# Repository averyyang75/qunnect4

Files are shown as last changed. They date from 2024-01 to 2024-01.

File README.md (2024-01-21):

# Qunnect4

---

Qunnect4 is designed as an educational board game rooted in the principles of quantum mechanics. With using simulated bichromatic photons, it illustrates the counterintuitive aspects of quantum phenomena and explains fundamental concepts such as superposition, collapse, and entanglement. By encapsulating quantum physics within a physical board game format, Qunnect4 bridges the mysterious realm of quantum physics with the classical world, providing a straightforward, interactive and hands-on experience.

## Construction of Apparatus

Qunnect4 consists of 42 tokens and 1 game board.

Each token is made with a PCB, assembled with one blue and one red LED, two resistors, four diodes, one radio transmitter and one receiver, four push buttons, and one battery holder. Powered by a battery, a token simulates a bichromatic photon. The token is superposed when turned on initially, emitting both blue and red LEDs. When a red or blue button is pushed, the token collapses, emitting only one LED.

The 42 tokens are grouped into 21 pairs. Each pair of tokens simulate a pair of “entangled photons”, with using the paired radio modules. Measuring one token will collapse both tokens simultaneously (one red and one blue).

The game board can be made with wood or foam board.

## Use of Apparatus

As a quantum adaptation of the popular game Connect 4, Qunnect4 is designed to provide hands-on experiences that help players quickly learn key quantum concepts such as superposition, collapse, and entanglement with ease.

Players are encouraged to use the apparatus in a manner like playing Connect 4, with following differences:

- In classic Connect 4, each player places 1 token each turn.
- In Qunnect 4, each player places a pair of entangled tokens each turn.
- A player may choose not to place tokens. Instead, the player can press a button to
collapse a pair of entangled tokens on board.
- To prevent a cycling condition, where one player always collapses the tokens placed by
the other, a player is not allowed to collapse a token unless its row or column is fully occupied. This rule ensures a fair and balanced gameplay experience for both players.

## Related Projects

[Qunnect4 Web](https://github.com/averyyang75/qunnect4-web) implements Qunnect4 in the web application format, offering cost-free accessibility and improved availability.

[Qunnect4 Web game](https://qunnect4.app) is online now.

&copy; Avery Yang

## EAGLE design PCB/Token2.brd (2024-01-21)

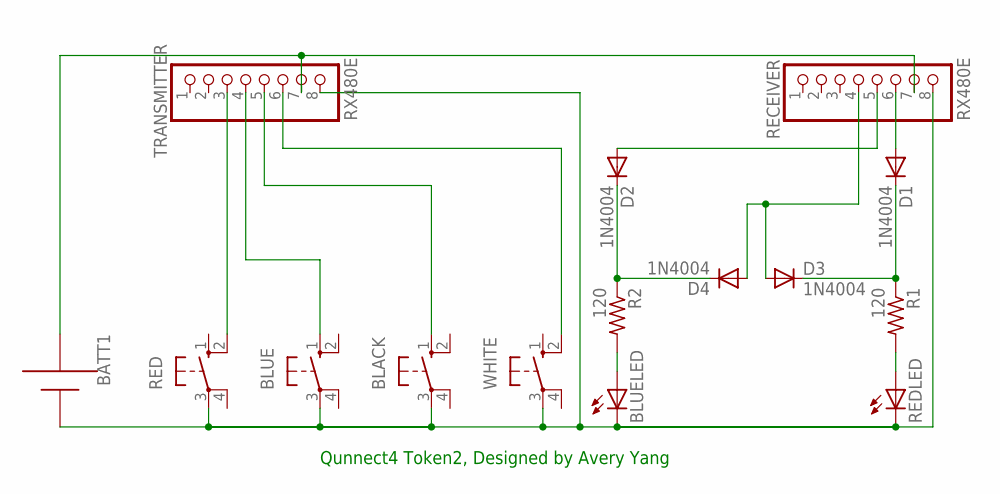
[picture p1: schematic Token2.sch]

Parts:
BATT1: AAA; 12BH412
BLACK: 10-XX; B3F-10XX
BLUE: 10-XX; B3F-10XX
BLUELED: LED5MM
D1, D2, D3, D4: 1N4004; DO41-10
R1, R2: 120; 0207/10
RECEIVER: RX480E; 1X08
RED: 10-XX; B3F-10XX
REDLED: LED5MM
TRANSMITTER: RX480E; 1X08
WHITE: 10-XX; B3F-10XX

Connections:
unnamed: BATT1.+, BLACK.3, BLUE.3, BLUELED.K (C), RECEIVER.8, RED.3, REDLED.K (C), TRANSMITTER.8, WHITE.3
unnamed: D2.C, D4.C, R2.1
unnamed: TRANSMITTER.6, WHITE.2 (S1)
unnamed: BLUE.1 (S), TRANSMITTER.4
unnamed: RED.2 (S1), TRANSMITTER.3
unnamed: BLACK.1 (S), TRANSMITTER.5
unnamed: D2.A, RECEIVER.5
unnamed: D1.A, RECEIVER.6
unnamed: D1.C, D3.C, R1.1
unnamed: R1.2, REDLED.A
unnamed: BLUELED.A, R2.2
unnamed: D3.A, D4.A, RECEIVER.4
unnamed: BATT1.-, RECEIVER.7, TRANSMITTER.7

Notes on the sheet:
Qunnect4 Token2, Designed by Avery Yang

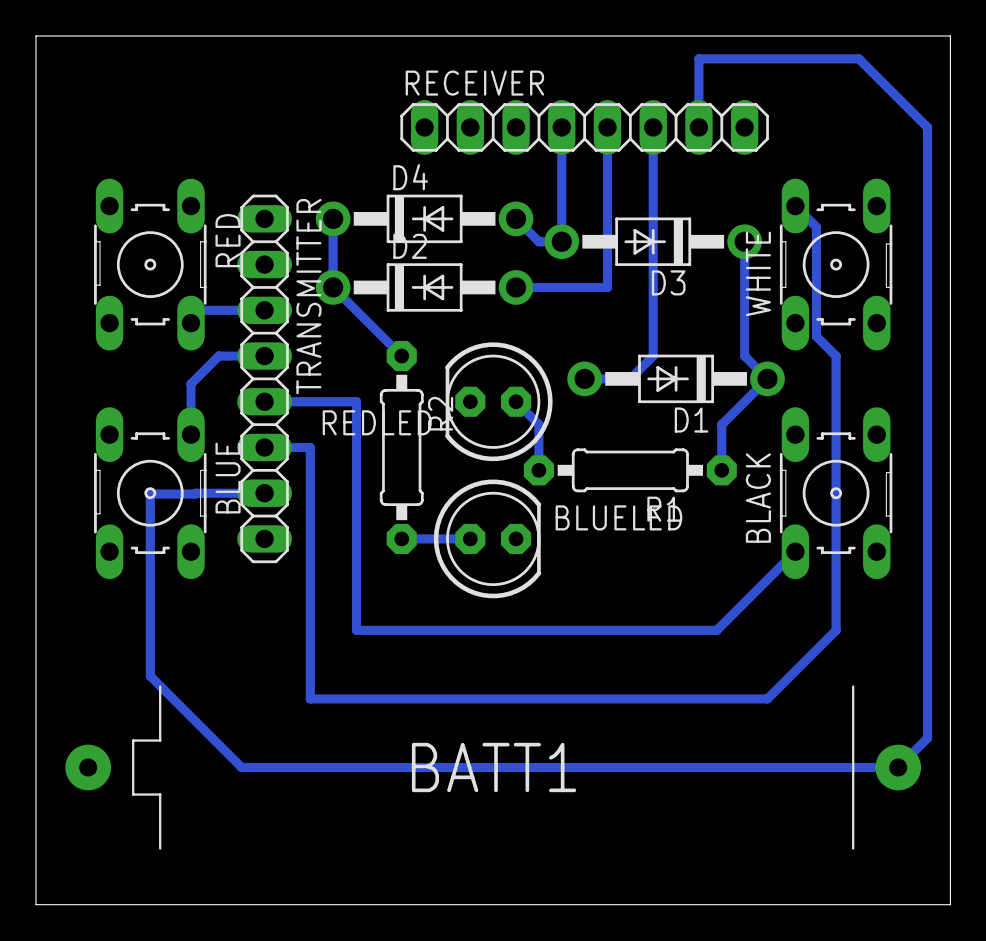
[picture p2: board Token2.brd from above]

Board: 2 copper layers, 50.8 x 48.3 mm, 15 parts (0 on the bottom side), 13 nets.

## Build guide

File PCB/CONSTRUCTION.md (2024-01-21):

# Construction

Each token is represented by a PCB. As tokens are grouped in pairs, there are two different designs of PCBs.

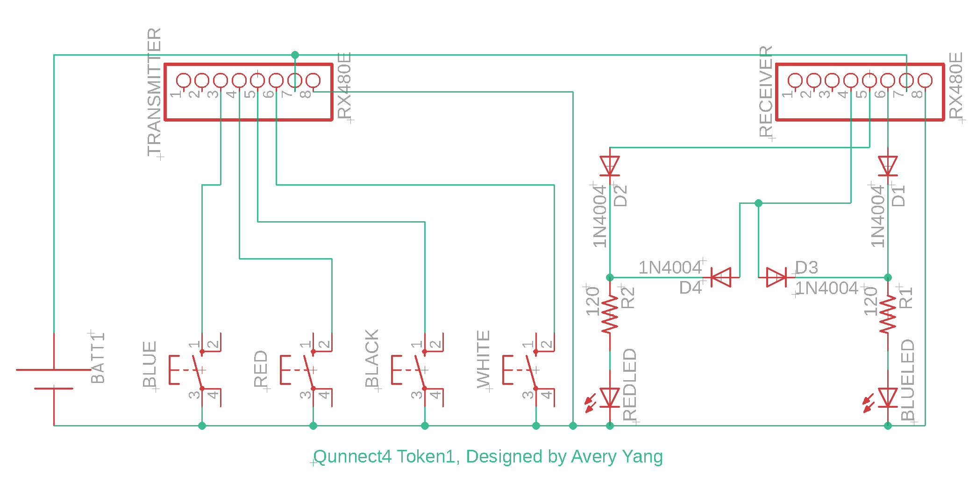
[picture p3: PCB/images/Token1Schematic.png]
Token 1 Schematic Design

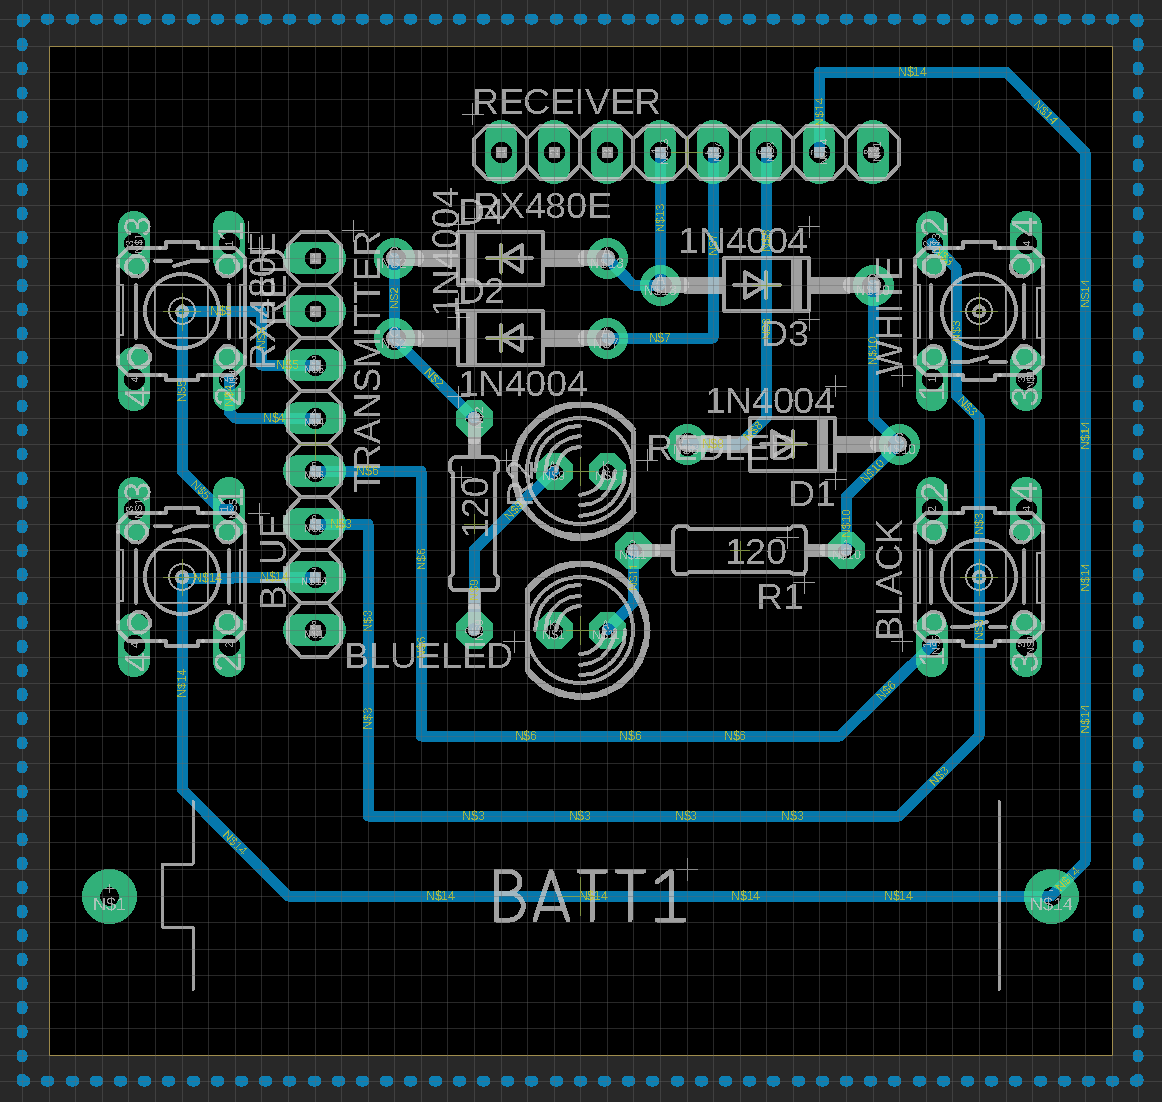
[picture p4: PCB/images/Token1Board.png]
Token 1 Board Design

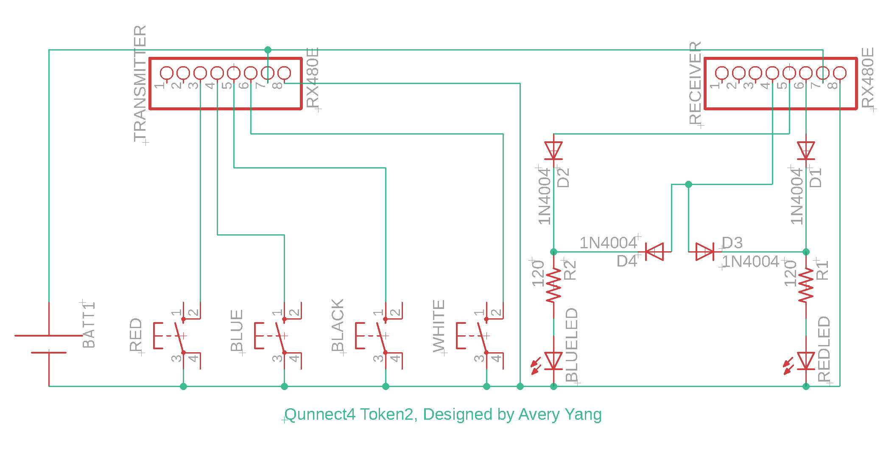
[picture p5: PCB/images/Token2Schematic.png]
Token 2 Schematic Design

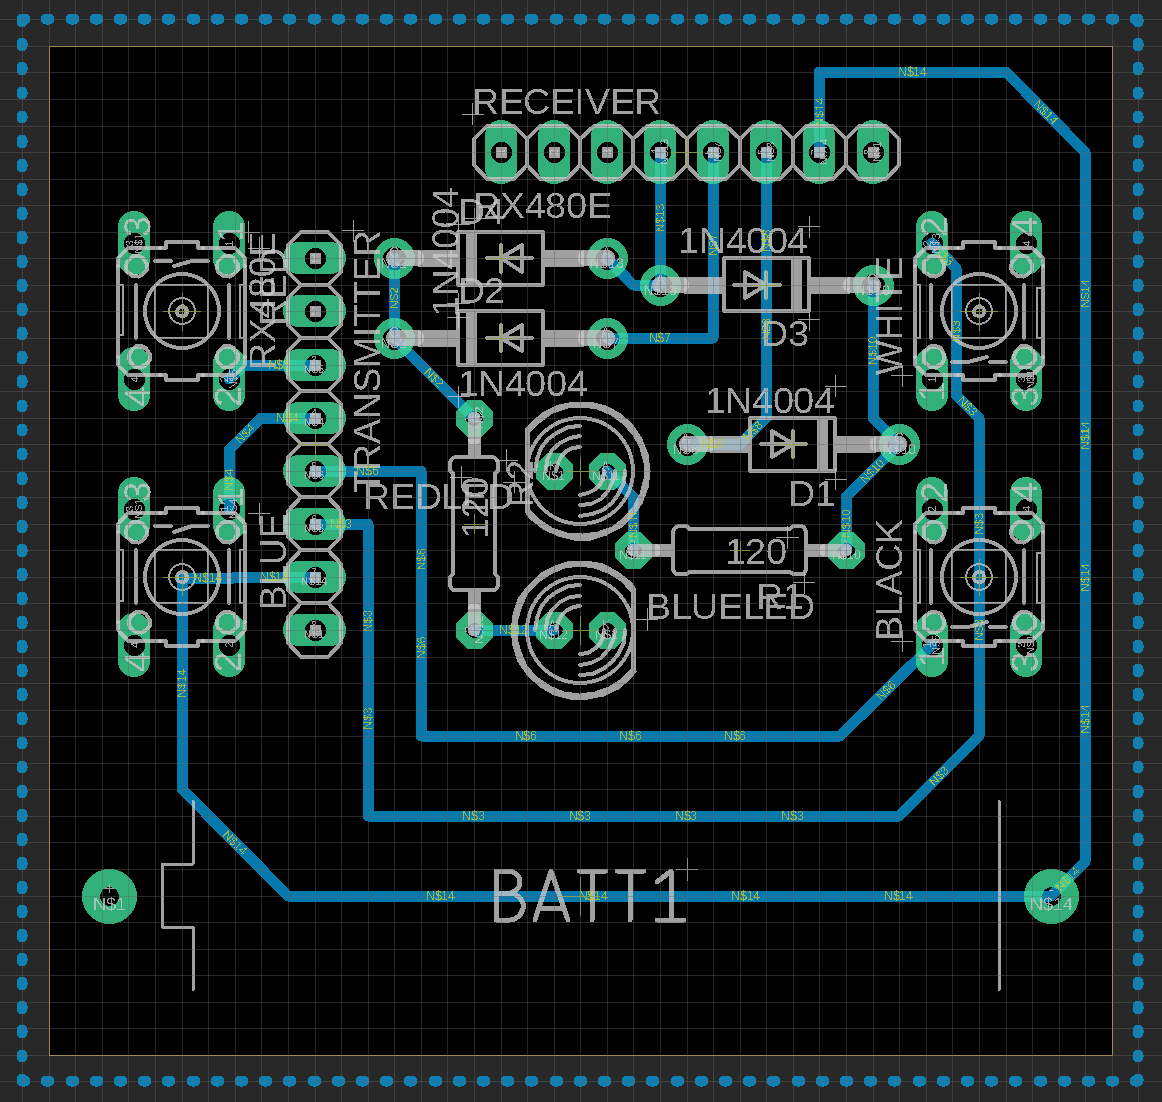
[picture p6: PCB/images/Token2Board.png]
Token 2 Board Design


Each PCB is assembled with one blue and one red LED, two resistors (120ohm), four diodes (1N5817), one radio transmitter and one receiver (QIACHIP RX480E), four push button switches, and one battery holder. Powered by a 3.7v Lithium battery (ICR 10440), a token simulates a bichromatic photon.

To achieve the effect of entanglement, the radio modules on both tokens need to be self-paired and cross-paired. In other words, the receiver on each token needs to learn both transimtters. Please refer to the user manual of the QIACHIP RX480E about procedures to pair the radio modules.

&copy; Avery Yang
